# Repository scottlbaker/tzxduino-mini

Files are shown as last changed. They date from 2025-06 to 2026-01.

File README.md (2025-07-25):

## Summary

A digital tape player for vintage computers

## Description

The TZXDuino is an open-source device used to play digital recordings of cassette tapes on retro computers like the ZX80, ZX81, ZX-Spectrum and Amstrad CPC. The TZXduino-mini places an ATmega328 processor directly on the PCB rather than using an Arduino Nano.

## Firmware

The TZXduini-mini firmware is a fork of the open source TZXduino firmware.

## Contributors

* Scott L Baker
* Craig Miles

## License

See the **LICENSE** file in this repository

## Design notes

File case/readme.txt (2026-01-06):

There are 2 options to make the case top:

a) use top.stl to 3D print a top
b) make a circuit board using the top.zip file

If you use the 3D file then you can use text.pdf to print labels

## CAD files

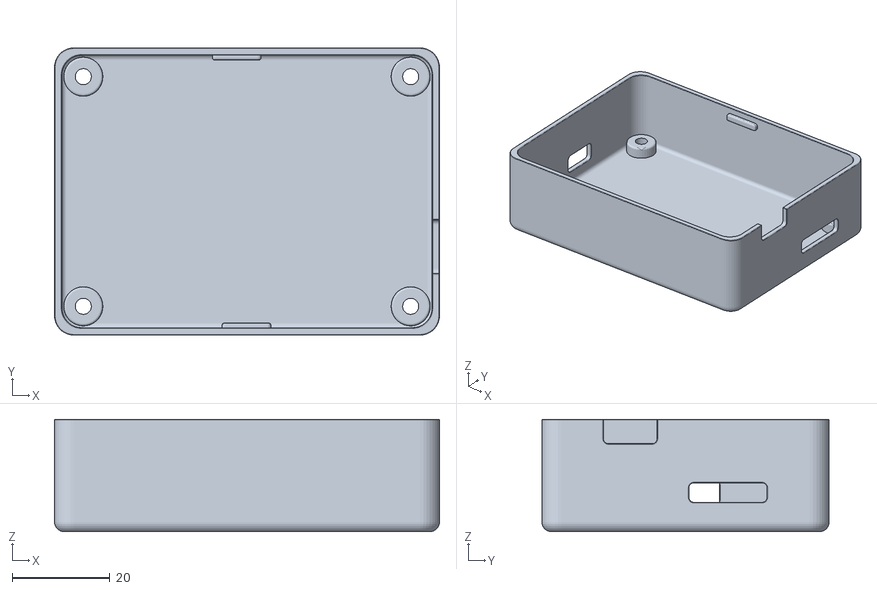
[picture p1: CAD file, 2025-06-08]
case/base.stl
78.8 x 58.8 x 23.0

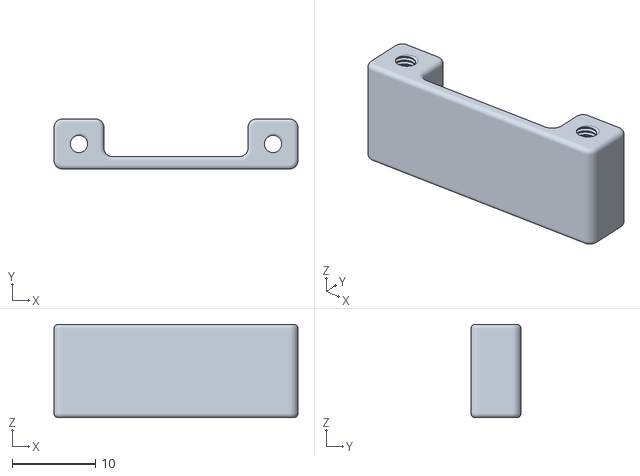
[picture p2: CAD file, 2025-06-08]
case/lcd-standoff.stl
29.3 x 6.00 x 11.2

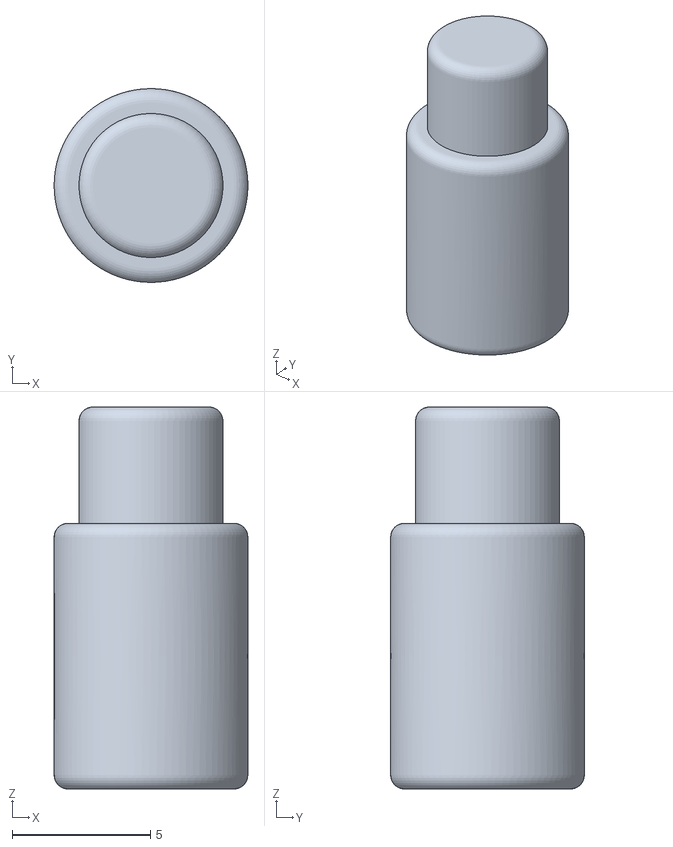
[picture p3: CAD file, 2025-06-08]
case/button.stl
7.00 x 7.00 x 13.8

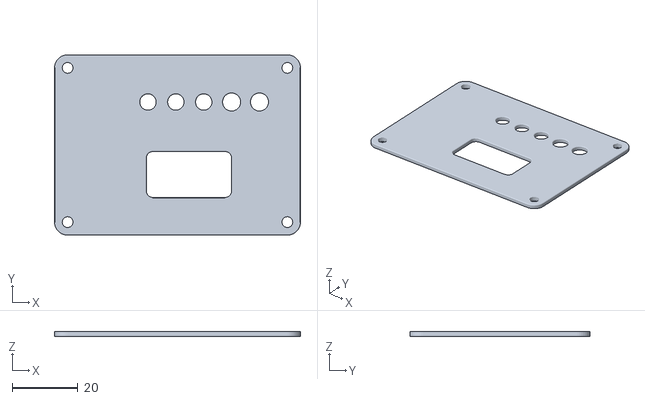
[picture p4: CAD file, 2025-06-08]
case/top.stl
75.0 x 55.0 x 1.60

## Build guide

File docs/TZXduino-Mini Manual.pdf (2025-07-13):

# TZXDuino-Mini Manual

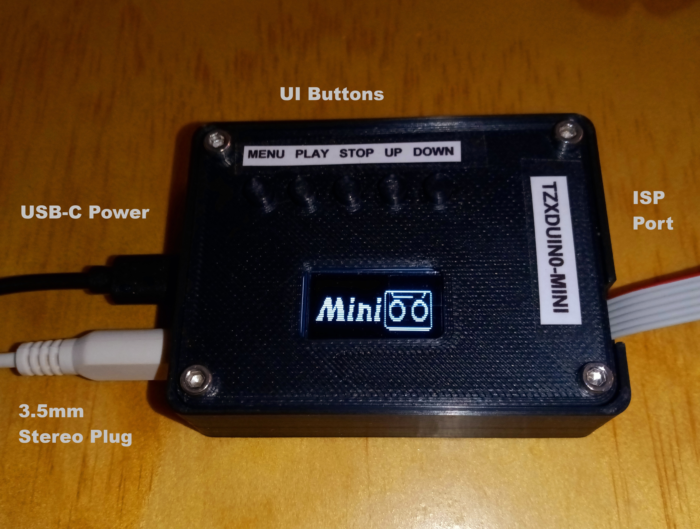
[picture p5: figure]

Buttons

### 1. Menu – Bring up a menu to allow you to change settings

### 2. Play/Pause – For playback and also for menu item selection

### 3. Stop – For playback and also to exit the menu

### 2. Up – For file or menu selection

### 1. Down – For file or menu selection

Connectors

1. 3.5mm Stereo Audio EAR socket

### 2. USB-C Power

### 3. ISP (Arduino programming port)

Cables

1. 3.5mm mono-to-stereo Audio cable **

### 2. USB-C power cable

### 3. Arduino programming cable (optional)

** In my experience a mono plug is slightly longer and it won't seat into the TZXduino-Mini stereo jack which may lead to failure of the stereo jack. For this reason a custom mono-to-stereo cable (stereo on the TZXduino side and mono on the TS1000 side) is recommended.

SD Card

### 1. FAT32 Formatted Micro SD card to store files **

** Class 4 or higher is recommended. Some experimentation and testing may be needed to find a reliable SD card. Because of the way the Arduino software works the file organization is based on when the files went on the SD card and not alphabetically. If you want the SD Card organized alphabetically a program like FATSorter can be used to organize your SD Card.

Menu

The Menu has the following options

### 1. Baud rate -- select 1200, 2400, and 3600 baud

### 2. Turbo Boost (On/Off) – enables faster loads for the ZX80/81, Oric, and

Acorn Electron. If you are using any other machine this should be off.

### 3. Pause @ Start (On/Off) – control whether the file pauses when you first

press play.

### 4. Gremlin Loader (On/Off) – This should be off for most games. To the best

of my knowledge it only needed for Footballer Of The Year on the CPC.

Supported File Types

TZXDuino can play the following file types ZX Spectrum: TZX, TAP, and AY. ZX80: P, TZX ZX81: O, TZX Amstrad CPC: CDT Acorn Electron: UEF ** BBC Microcomputer: UEF

1
Jupiter ACE: TZX ORIC: TAP

** UEF files need to be unzipped before they can be played on the TZXDuino. On Linux machines this can be done by using GUNZIP. On Windows machines this involves using WinZIP or WinRAR to decompress the UEF file. Once decompressed you will have a file with either no extension or a .hq extension. Rename the file to add .UEF on the end. Example Rename JetSetWilly_B.hq to JetSetWilly_B.hq.UEF

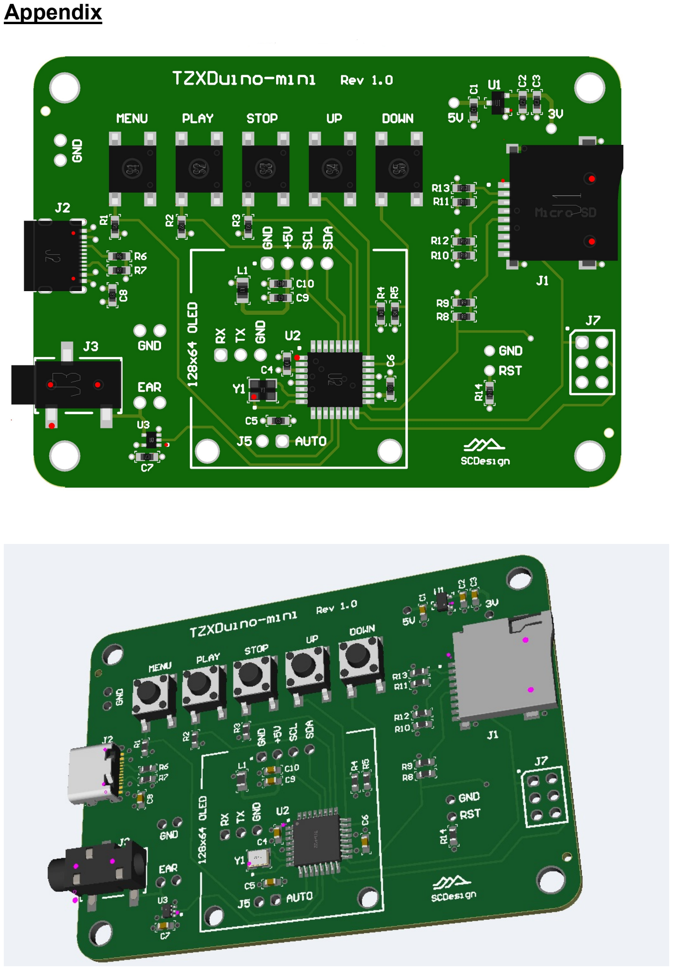
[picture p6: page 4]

Appendix

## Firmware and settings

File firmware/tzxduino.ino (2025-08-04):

//=========================================================================
//
//  tzxduino.ino  -- main file
//
//=========================================================================

#define VERSION "TZX-Mini 1.17a"
#define DATE    "Jul-23-2025"

// ========================================================================
//
// Load TZX files onto an SD card, and play them directly
//
// The original TZXduino code was written and tested by
// Andrew Beer and Duncan Edwards. It was written using info from
// worldofspectrum.org and TZX2WAV by Francisco Javier Crespo
//
// ========================================================================
//
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
// ========================================================================

#include <Wire.h>
#include <EEPROM.h>
#include <SdFat.h>
#include "TZXDuino.h"

// instantiate the file system
SdFat  sd;
SdFile file;

// initialize pins
void init_pins() {
  pinMode(outputPin,  OUTPUT);
  pinMode(chipSelect, OUTPUT);
  digitalWrite(outputPin, LOW);
  pinMode(btnPlay,    INPUT_PULLUP);
  pinMode(btnStop,    INPUT_PULLUP);
  pinMode(btnUp,      INPUT_PULLUP);
  pinMode(btnDown,    INPUT_PULLUP);
  pinMode(btnMotor,   INPUT_PULLUP);
  pinMode(btnRoot,    INPUT_PULLUP);
  pinMode(btnMenu,    INPUT_PULLUP);
}

// init timer1
void init_timer1() {
  TIMSK1 = 0x00;           // disable timer1 interrupt
  TCCR1A = 0x00;           // CTC mode
  TCCR1B = 0x0a;           // prescaler 8
  OCR1A  = 0xfff0;         // load end count
  TCNT1  = 0x00;           // clear timer
}

// initial setup
void setup() {
  init_pins();                      // init pins
  init_timer1();                    // init timer1
  Serial.begin(115200);             // init UART
  Wire.begin();                     // init I2C
  init_OLED();                      // init display
  showLogo();                       // show logo

  // start SD card and check that it's working
  if (!sd.begin(chipSelect,SPI_FULL_SPEED)) {
    printtextF(PSTR("No SD Card"),0);
    return;
  }
  sd.chdir();               // set SD to root directory
  TZXSetup();               // setup TZX specific options

  EEPROM.get(0,settings);
  EEPROM.get(1,turboBitGap);
  // check BitGap and default to 500 if not configured yet
  if(turboBitGap < 1 || turboBitGap > ZX81BITGAP) turboBitGap = 500;
  baudRate = settings & BAUD_BITS;
  timeDiff = millis();     // get current millisecond count
  getMaxFile();            // get the total number of files in the directory
  seekFile(currentFile);   // move to the first file in the directory
  if((settings & HIDE_BIT) && (fileName[0] == '.')) downFile();
  updateDisplay();
}

// main loop
void loop(void) {

  if (start==1) {
    TZXLoop();
  } else {
    digitalWrite(outputPin, LOW);    // output LOW when idle
  }

  if ((millis()>=scrollTime) && start==0 && (strlen(fileName)>15)) {
    // filename scrolling only runs if no file is playing to prevent I2C writes
    // conflicting with the playback Interrupt
    scrollTime = millis()+SCROLLSPEED;
    scrollText(fileName);
    scrollPos +=1;
    if (scrollPos>strlen(fileName)) {
      scrollPos=0;
      scrollTime=millis()+SCROLLWAIT;
      scrollText(fileName);
    }
  }
  motorState=digitalRead(btnMotor);
  if (millis() - timeDiff > 50) {   // check switch every 50ms
    timeDiff = millis();            // get current millisecond count

    if (MENU_PRESSED && start==0) {
      menuMode();
      updateDisplay();
    }

    if (PLAY_PRESSED) {
      // handle Play/Pause button
      if (start==0) {
        // if no file is play, start playback
        playFile();
        // showFileSize();  // for debug only
        delay(200);
      } else {
        // if a file is playing, pause or unpause the file
        if (pauseOn == 0) {
          printtextF(PSTR("Paused"),0);
          showPercent();
          showTime();
          pauseOn = 1;
        } else {
          printtextF(PSTR("Playing"),0);
          showPercent();
          pauseOn = 0;
        }
      }
      while (PLAY_PRESSED) {
        // wait until button is released
        delay(200);
      }
    }

    if (STOP_PRESSED && start==1) {
      stopFile();
      // wait until the button is released
      while (STOP_PRESSED) {
        delay(200);
      }
    }
    if (STOP_PRESSED && start==0 && subdir >0) {
      fileName[0]='\0';
      prevSubDir[subdir-1][0]='\0';
      subdir--;
      switch(subdir) {
       case 1:
         // sprintf(fileName,"%s%s",prevSubDir[0],prevSubDir[1]);
         sd.chdir(strcat(strcat(fileName,"/"),prevSubDir[0]),true);
         break;
       case 2:
         // sprintf(fileName,"%s%s/%s",prevSubDir[0],prevSubDir[1],prevSubDir[2]);
         sd.chdir(strcat(strcat(strcat(strcat(fileName,"/"),prevSubDir[0]),"/"),prevSubDir[1]),true);
         break;
      case 3:
         // sprintf(fileName,"%s%s/%s/%s",prevSubDir[0],prevSubDir[1],prevSubDir[2],prevSubDir[3]);
         sd.chdir(strcat(strcat(strcat(strcat(strcat(strcat(fileName,"/"),prevSubDir[0]),"/"),prevSubDir[1]),"/"),prevSubDir[2]),true);
         break;
       default:
         // sprintf(fileName,"%s",prevSubDir[0]);
         sd.chdir("/",true);
       }
       // return to prev Dir of the SD card.
       // sd.chdir(fileName,true);
       // sd.chdir("/CDT");
       // printtext(prevDir,0); // debug back dir
       getMaxFile();
       currentFile=1;
       seekFile(currentFile);
       if((settings & HIDE_BIT) && (fileName[0] == '.')) downFile();
       updateDisplay();
       while (STOP_PRESSED) {
         // prevent button repeats by waiting until the button is released.
         delay(200);
       }
     }

     if (start==0) {
        if (DOWN_PRESSED) {
          // move down a file in the directory
          scrollTime=millis()+SCROLLWAIT;
          scrollPos=0;
          downFile();
          delay(browseDelay);
          reduceBrowseDelay();
        }

       else if (UP_PRESSED) {
         // move up a file in the directory
         scrollTime=millis()+SCROLLWAIT;
         scrollPos=0;
         upFile();
         delay(browseDelay);
         reduceBrowseDelay();
       }
       else {
        resetBrowseDelay();
       }
     }

     if (start==1 && (!oldMotorState==motorState)) {
       // motor control works by pulling the btnMotor to GND to play
       if (motorState==1 && pauseOn==0) {
         printtextF(PSTR("Paused"),0);
         showPercent();
         showTime();
         pauseOn = 1;
       }
       if (motorState==0 && pauseOn==1) {
         printtextF(PSTR("Playing"),0);
         showPercent();
         pauseOn = 0;
       }
       oldMotorState=motorState;
     }
  }
}

byte NO_BUTTON_PRESSED() {
  byte buttons = PINC;
  byte mask = 0x0F;
  delay(10);
  if ((buttons & mask) == mask) return 1;
  else return 0;
}

void reduceBrowseDelay() {
  if (browseDelay >= 100) {
    browseDelay -= 100;
  }
}

void resetBrowseDelay() {
  browseDelay = 500;
}

void upFile() {
  do {
    // move up a file in the directory
    currentFile--;
    if (currentFile<1) {
      getMaxFile();
      currentFile = maxFile;
    }
    UP=1;
    seekFile(currentFile);
  } while((settings & HIDE_BIT) && (fileName[0] == '.'));
  updateDisplay();
}

void downFile() {
  do {
    // move down a file in the directory
    currentFile++;
    if (currentFile>maxFile) { currentFile=1; }
    UP=0;
    seekFile(currentFile);
  } while((settings & HIDE_BIT) && (fileName[0] == '.'));
  updateDisplay();
}

void seekFile(int pos) {
  // move to a set position in the directory
  // store the filename, and display the name on screen
  if (UP==1) {
    file.cwd()->rewind();
    for (int i=1;i<=currentFile-1;i++) {
      file.openNext(file.cwd(),O_READ);
      file.close();
    }
  }
  if (currentFile==1) {file.cwd()->rewind();}
  file.openNext(file.cwd(),O_READ);
  file.getName(fileName,FILENAMELENGTH);
  file.getSFN(sfileName);
  fileSize = file.fileSize();
  ayblklen = fileSize + 3;  //  add 3 file header, data byte and chksum byte to file length
  if (file.isDir() || !strcmp(sfileName, "ROOT")) { isDir=1; } else { isDir=0; }
  file.close();
}

void updateDisplay() {
  printtextF(PSTR("Select File.."),0);
  scrollPos=0;
  scrollText(fileName);
}

void stopFile() {
  TZXStop();
  if (start==1) {
    printtextF(PSTR("Stopped"),0);
    showPercent();
    showTime();
    clearLine(2);
    start=0;
  }
}

void playFile() {
  if (isDir==1) {
    // if selected file is a directory move into directory
    changeDir();
  } else {
    if (file.cwd()->exists(sfileName)) {
      printtextF(PSTR("Playing"),0);
      scrollPos=0;
      if (!(settings & PAUSE_BIT)) pauseOn = 0;
      scrollText(fileName);
      currpct=0;
      timeCount=0;
      timeDiff2 = millis();         // reset millisecond count
      TZXPlay(sfileName);           // load using the short filename
      start=1;
      if (settings & PAUSE_BIT) {
        printtextF(PSTR("Paused"),0);
        pauseOn = 1;
        TZXPause();
      }
    } else {
      printtextF(PSTR("No File Selected"),1);
    }
  }
}

void getMaxFile() {
  // gets the total files in the current directory and stores the number in maxFile
  file.cwd()->rewind();
  maxFile=0;
  while (file.openNext(file.cwd(),O_READ)) {
    // file.getName(fileName,FILENAMELENGTH);
    file.close();
    maxFile++;
  }
  file.cwd()->rewind();
}

void changeDir() {
  // change directory, if fileName="ROOT" then return to the root directory
  // sdfat has no easy way to move up a directory, so returning to root is the easiest way.
  // each directory (except the root) must have a file called ROOT (no extension)
  if (!strcmp(fileName, "ROOT")) {
    subdir=0;
    sd.chdir(true);
  } else {
     if (subdir >0) file.cwd()->getName(prevSubDir[subdir-1],FILENAMELENGTH);
     sd.chdir(fileName, true);
     subdir++;
  }
  getMaxFile();
  currentFile=1;
  seekFile(currentFile);
  if((settings & HIDE_BIT) && (fileName[0] == '.')) downFile();
  updateDisplay();
}

void scrollText(char* text) {
  // text scrolling routine. Setup for 16x2 screen so will only display 16 chars
  if (scrollPos<0) scrollPos=0;
  char outtext[17];
  if (isDir) { outtext[0]= 0x3E;
    for (int i=1;i<16;i++) {
      int p=i+scrollPos-1;
      if (p<strlen(text)) {
        outtext[i]=text[p];
      } else {
        outtext[i]='\0';
      }
    }
  } else {
    for (int i=0;i<16;i++) {
      int p=i+scrollPos;
      if (p<strlen(text)) {
        outtext[i]=text[p];
      } else {
        outtext[i]='\0';
      }
    }
  }
  outtext[16]='\0';
  printtext(outtext,1);
}

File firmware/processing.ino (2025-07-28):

//=========================================================================
//
//  processing.ino  -- data processing routines used by tzxduino.ino
//
//=========================================================================

int readfile (byte bytes, unsigned long p) {
  int i = 0;
  int t = 0;
  if (file.seekSet (p)) {
    i = file.read (inputBuf, bytes);
  }
  return i;
}

void clearBuffer () {
  for (int i = 0; i <= buffsize; i++) {
    wbuffer[i][0] = 0;
    wbuffer[i][1] = 0;
  }
}

void printID() {
  byte x;
  switch (currentID) {
  case EOF:
    printtextF (PSTR ("EOF"), 2);
    break;
  default:
    printtextF (PSTR ("ID"), 2);
    setXY (2, 2);
    x = (currentID>>4);
    if (x < 10) sendChar (x+48);
    else sendChar (x+87);
    x = currentID & 0x0f;
    if (x < 10) sendChar (x+48);
    else sendChar (x+87);
    break;
  }
}

bool checkForTap (char *filename) {
  // Check for TAP file extensions as these have no header
  byte len = strlen(filename);
  if (strstr_P (strlwr(filename + (len - 4)), PSTR (".tap"))) {
    return true;
  }
  return false;
}

bool checkForP (char *filename) {
  // Check for P file extensions as these have no header
  byte len = strlen(filename);
  if (strstr_P (strlwr(filename + (len - 2)), PSTR (".p"))) {
    return true;
  }
  return false;
}

bool checkForO (char *filename) {
  // Check for O file extensions as these have no header
  byte len = strlen(filename);
  if (strstr_P (strlwr(filename + (len - 2)), PSTR (".o"))) {
    return true;
  }
  return false;
}

bool checkForAY (char *filename) {
  // check for AY File (need to create Tap header)
  byte len = strlen(filename);
  if (strstr_P (strlwr(filename + (len - 3)), PSTR (".ay"))) {
    return true;
  }
  return false;
}

bool checkForUEF (char *filename) {
  // check for UEF File (need to create Tap header)
  byte len = strlen(filename);
  if (strstr_P (strlwr(filename + (len - 4)), PSTR (".uef"))) {
    return true;
  }
  return false;
}

void UEFCarrierToneBlock() {
  // pure Tone Block - Long string of pulses with the same length
  currentPeriod = pilotLength;
  pilotPulses -= 1;
  if (pilotPulses==0) {
    currentTask = GETCHUNKID;
  }
}

void writeUEFData() {
  // convert byte from file into string of pulses.. one pulse per pass
  byte r;
  if (currentBit==0) {                         // check for byte end/first byte
    if (r=ReadByte(bytesRead)==1) {            // read in a byte
      currentByte = outByte;
      bytesToRead -= 1;
      bitChecksum = 0;
      if (bytesToRead == 0) {                  // check for end of data block
        lastByte = 1;
        if (pauseLength==0) {                  // search for next ID if there is no pause
          currentTask = PROCESSCHUNKID;
        } else {
          currentBlockTask = PAUSE;            // otherwise start the pause
        }
        // return;                             // exit
      }
    } else if (r==0) {                         // if we reached the EOF
      currentTask = GETCHUNKID;
    }
    currentBit = 11;
    pass=0;
  }
  if ((currentBit == 2) && (parity == 0)) currentBit = 1;
  if (currentBit == 11) {
    currentPeriod = zeroPulse;
  } else if (currentBit == 2) {
    currentPeriod = (bitChecksum ^ (parity & 0x01)) ? onePulse : zeroPulse;
  } else if (currentBit == 1) {
      currentPeriod = onePulse;
  } else {
    if (currentByte&0x01) {                       // set next period depending on value of bit 0
      currentPeriod = onePulse;
    } else {
      currentPeriod = zeroPulse;
    }
  }
  pass+=1;      // data is played as 2 x pulses for a zero, and 4 pulses for a one when speed is 1200
  if (currentPeriod == zeroPulse) {
    if (pass==passforZero) {
       if ((currentBit>1) && (currentBit<11)) {
         currentByte >>= 1;                        // shift along to the next bit
       }
       currentBit -= 1;
       pass=0;
       if ((lastByte) && (currentBit==0)) {
         currentTask = GETCHUNKID;
       }
    }
  } else {
    // must be a one pulse
    if (pass==passforOne) {
      if ((currentBit>1) && (currentBit<11)) {
        bitChecksum ^= 1;
        currentByte >>= 1;                        // shift along to the next bit
      }
      currentBit -= 1;
      pass=0;
      if ((lastByte) && (currentBit==0)) {
        currentTask = GETCHUNKID;
      }
    }
  }
}

void OricDataBlock () {
  // convert byte from file into string of pulses
  byte r;
  if (currentBit == 0) {                    // check for byte end/first byte
    if (r = ReadByte(bytesRead) == 1) {     // read in a byte
      currentByte = outByte;
      bytesToRead -= 1;
      bitChecksum = 0;
      if (bytesToRead == 0) {               // check for end of data block
        lastByte = 1;
      }
    } else if (r == 0) {                    // if we reached the EOF
      EndOfFile = true;
      temppause = 0;
      bufCount = 255;
      currentID = IDPAUSE;
      return;
    }
    currentBit = 11;
    pass = 0;
  }
  OricBitWrite();
}

void OricBitWrite () {
  if (currentBit == 11) {   //Start Bit
    if (pass == 0) currentPeriod = ORICZEROLOWPULSE;
    if (pass == 1) currentPeriod = ORICZEROHIGHPULSE;
  } else if (currentBit == 2) {   // inverse parity
    if (pass == 0) currentPeriod = bitChecksum ? ORICZEROLOWPULSE : ORICONEPULSE;
    if (pass == 1) currentPeriod = bitChecksum ? ORICZEROHIGHPULSE : ORICONEPULSE;
  } else if (currentBit == 1) {
    currentPeriod = ORICONEPULSE;
  } else {
    if (currentByte & 0x01) {                      // set next period depending on value of bit 0
      currentPeriod = ORICONEPULSE;
    } else {
      if (pass == 0) currentPeriod = ORICZEROLOWPULSE;
      if (pass == 1) currentPeriod = ORICZEROHIGHPULSE;
    }
  }
  pass += 1;
  if (currentPeriod == ORICONEPULSE) {
    if ((currentBit > 2) && (currentBit < 11) && (pass == 2)) {
      bitChecksum ^= 1;
      currentByte >>= 1;                           // shift along to the next bit
      currentBit -= 1;
      pass = 0;
    }
    if ((currentBit == 1) && (pass == 6)) {
      currentBit -= 1;
      pass = 0;
    }
    if (((currentBit == 2) || (currentBit == 11)) && (pass == 2)) {
      currentBit -= 1;
      pass = 0;
    }
    if ((currentBit == 0) && (lastByte)) {
      bufCount = 255;
      currentBlockTask = PAUSE;
    }
  } else {
    // must be a zero pulse
    if (pass == 2) {
      if ((currentBit > 2) && (currentBit < 11)) {
        currentByte >>= 1;
      }
      currentBit -= 1;
      pass = 0;
      if ((currentBit == 0) && (lastByte)) {
        bufCount = 255;
        currentBlockTask = PAUSE;
      }
    }
  }
}

word TickToUs (word ticks) {
  return (word)((((float)ticks) / 3.5) + 0.5);
}
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

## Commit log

2025-06-08 added pcb zip file
    [base.stl, button.stl, lcd-standoff.stl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]
2025-07-27 replace timer1 routines
2025-07-28 new timer1 routines
2026-01-06 added top.zip gerber
2026-03-22 gerber file update
